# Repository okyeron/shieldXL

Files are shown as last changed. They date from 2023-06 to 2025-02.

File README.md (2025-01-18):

# shieldXL

A rework/remix of the monome norns shield - an open-source/DIY shield for Raspberry Pi boards, providing hardware compatibility with the [norns](https://monome.org/docs/norns) ecosystem. Original designed by monome (brian crabtree, aka @tehn). Remixed in spring 2023 by denki-oto.

__Please be very aware that this project is not directly supported by [monome](https://monome.org). Do not email monome asking for build help, debugging or repairs__

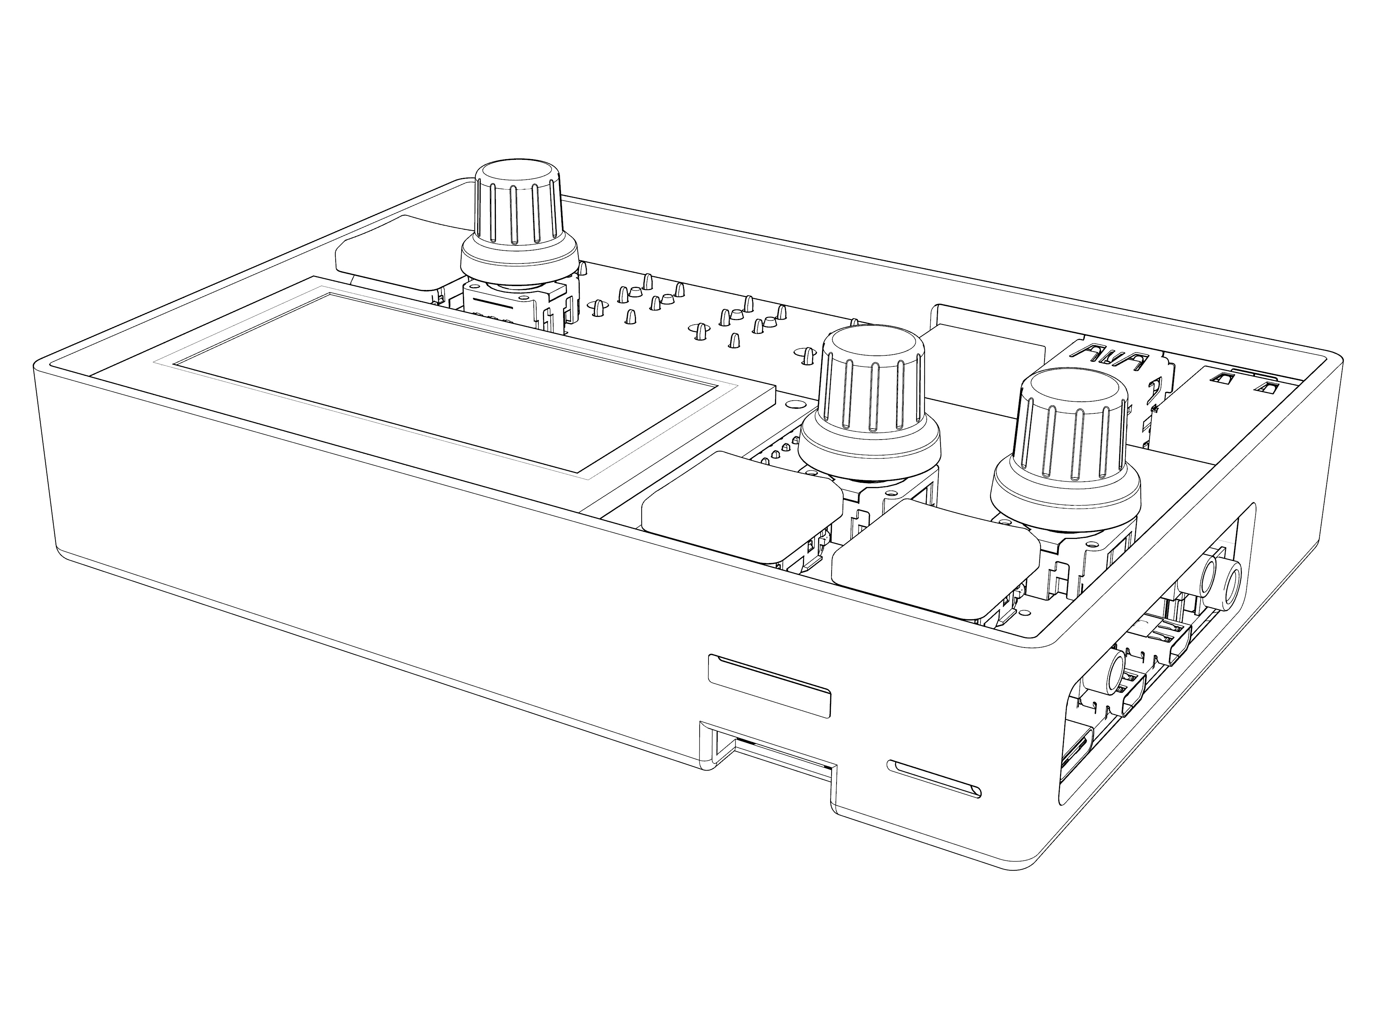
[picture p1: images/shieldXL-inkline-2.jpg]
<# shieldXL-inklinet #>


## specifications

- audio codec: CS4270  
- audio jacks: 6.5mm in and out, line level  
- OLED: NHD-2.7-12864WDW3-M (w/ MOLEX connector)  
- 3x pushbutton switches, 3x rotary encoders  
- dimensions (with enclosure): 138mm x 96mm x 30mm  

## versions

__shieldXL 20230423__
This rework/remix is based on the 210330 version of the norns shield. It uses the same disk image as the 210330 shield with the cs4270 codec.

## documentation

[See the monome website for general norns shield documentation](https://monome.org/docs/norns/shield/) 

## build

[Bill of Materials](bom/BOM.md)

[Build Guide](BUILD.md)

## installation

See [https://monome.org/docs/norns/help/#fresh-shield](https://monome.org/docs/norns/help/#fresh-shield) for installation instructions.  

See [norns releases on github](https://github.com/monome/norns-image/releases/tag/231114-img) for disk images (pre-211028 shield for cs4270 codec).   

Pi3 disk image:    
*  [norns231114-shield-pi3](https://github.com/monome/norns-image/releases/download/231114-img/norns231114-shield-pi3-cs4720.tgz)

Pi4 disk images (Try starting with 220306. If you get a blank screen, try starting over with 231114):  
* Pi4 220306 [norns220306-shield-pi4](https://github.com/monome/norns-image/releases/download/220306/norns220306-shield-pi4-cs4270.tgz)  
* Pi4 231114 [norns231114-shield-pi4](https://github.com/monome/norns-image/releases/download/231114-img/norns231114-shield-pi4-cs4720.tgz)  

REMEMBER TO EXPAND THE DISK IMAGE AFTER INSTALL  
[https://monome.org/docs/norns/shield/#expand-filesystem](https://monome.org/docs/norns/shield/#expand-filesystem)

## enabling hardware midi

```
cd ~
git clone https://github.com/okyeron/shieldXL.git
cd ~/shieldXL 
./install-midi.sh
```
(note - the install script will trigger a reboot)  

Then Edit `/boot/config.txt` 

`sudo nano /boot/config.txt`  

scroll to the bottom of the text and add the following at the end  
 
```
enable_uart=1
dtoverlay=miniuart-bt
dtoverlay=uart0
dtoverlay=midi-uart0
```
Then edit `/boot/cmdline.txt` 

`sudo nano /boot/cmdline.txt`  

and remove `serial0`    
(so change `console=serial0,115200` to `console=115200`)  
and `sudo reboot`  

This will internally connect the shieldXL hardware TRS MIDI jacks to the "Virtual MIDI" port which is accessible from the norns MIDI menu (SYSTEM>DEVICES>MIDI).  

__MIDI Troubleshooting__   

- When checking MIDI functionality, remember that MIDI OUT has a Type A/B switch on the bottom front edge of the main PCB. Try switching that if you're not getting MIDI to your device.

## mods

__Battery Modication__  
Add a Pisugar S Plus battery to your shieldXL:  https://github.com/JGuzak/shieldXl_battery  

## general troubleshooting

- Most soldering problems can be solved simply by reheating solder joints. Bad solders can result in various problems: screen doesn't turn on, knobs/keys don't work.
- Use a good SD card, not a cheap one. If you're having trouble, try using a different card.
- Be sure to use the correct power supply. The pi will not power well from a laptop and you'll get confusing errors. Get a dedicated 3A USB supply, or very high output USB battery.
- see the [norns documentation](https://monome.org/docs/norns/shield/) for help with the software  

## notes

- The shield does not have a dedicated headphone output, but headphones work fine on the main outputs (use the left output jack). The headphone gain level within the norns menu does nothing in this case.
- The battery indication will not function - there is no battery.

## License

[GNU GENERAL PUBLIC LICENSE](LICENSE.txt)

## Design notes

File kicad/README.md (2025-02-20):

# shieldXL 

Designed with [Kicad 8](https://www.kicad.org/)  

ShieldXL-M-20230615  

Based on the 210330 norns shield designed by monome. Remixed/redesigned march 2023 by steven noreyko/denki-oto.  

No official support - do not ask monome for help.   

Kicad files are provided "as-is". Pull requests or modifications to the original repository will not be accepted. No support/assistance can be provided for ordering or building PCBs from these files.

Open Source Hardware GPLv3.  See LICENSE.txt for details.

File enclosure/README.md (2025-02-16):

# shieldXL case/enclosure info

## credits

Models for 3D printing provided by CarlosUnch, John Park, rm, and Steven Noreyko  

Top panel files by Steven Noreyko  

## models for 3d printing

`shieldXL_case_v1.8.6` is the most recent and is optimized for commercial SLS Nylon printing. (from JLCPCB, etc.)  This version will need supports turned on for home FDM printers.  

`shieldXL_case_v1.8.6` also includes new "lids" (top panels) which can accomodate various switch/cap combos.  

`shieldXL_case_v1.4.4-FDM` is probably the simplest model for home FDM printers (PLA, etc.). 

Use the STL file for ordering from 3D printing services or printing yourself.  

Use the STEP file if you're wanting to customize/modify the model.  

Models are setup for M2.5 screws or for M2.5 threaded heat-press inserts.  

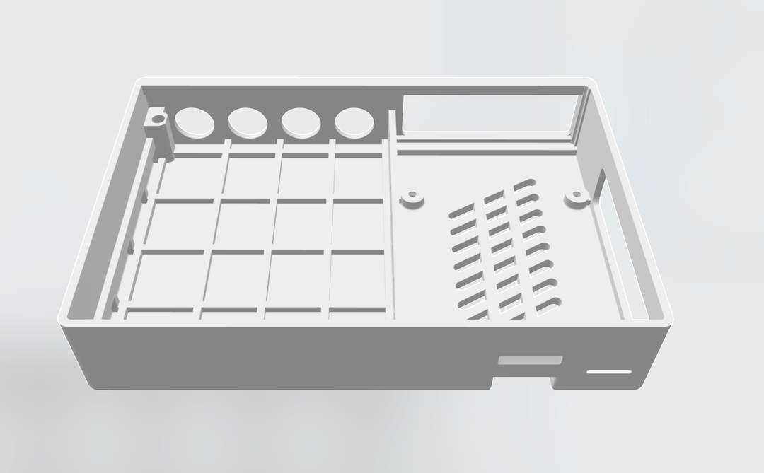
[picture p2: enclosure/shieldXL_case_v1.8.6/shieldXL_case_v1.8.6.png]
<# SLS Nylon caset #> shieldXL_case_v1.8.6
  

## dimensions

pcb dimensions: 132.7mm x 85mm  

top panel dimensions: 138mm x 92mm  

keyswitch holes: 19mm x 19mm

encoder holes: 8mm

mounting holes: 3mm

enclosure dimensions: 138mm x 96mm x 30mm  

## shieldsaver 

design by "rm"  [https://github.com/roge-rm](https://github.com/roge-rm)  

a "decksaver" cover for the standard 3d printed cases.

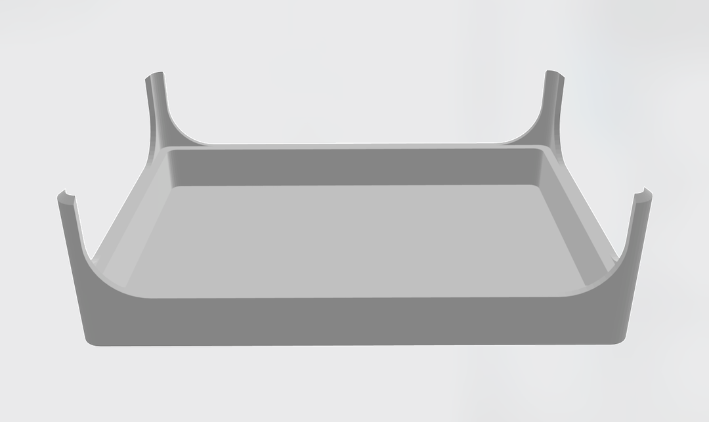
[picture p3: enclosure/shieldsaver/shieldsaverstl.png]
<# shieldsaver stl #> shieldsaver stl


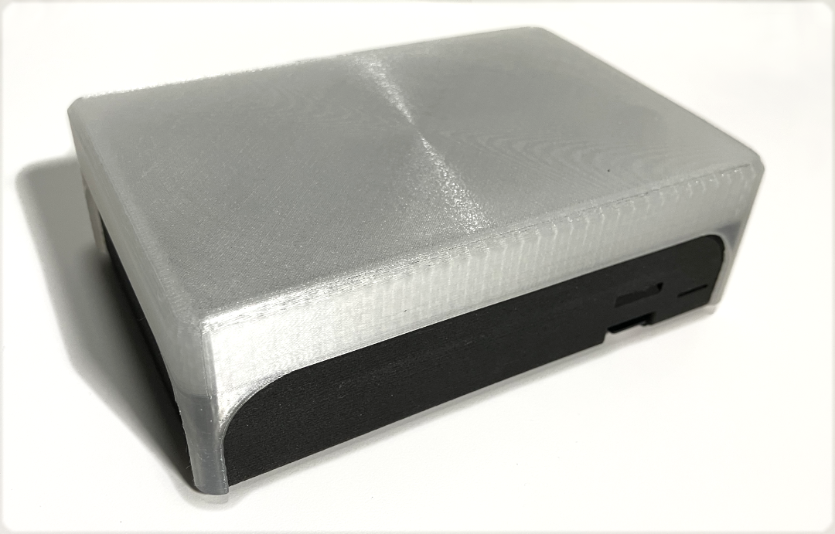
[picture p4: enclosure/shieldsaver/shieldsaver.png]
<# shieldsaver #>


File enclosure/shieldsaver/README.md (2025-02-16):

# shieldXL shieldsaver 

design by "rm"  [https://github.com/roge-rm](https://github.com/roge-rm)  

a "decksaver" cover for the standard 3d printed cases.

<# shieldsaver stl #> shieldsaver stl

<# shieldsaver #>

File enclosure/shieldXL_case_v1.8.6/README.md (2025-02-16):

# shieldXL Case

3D printable case for shieldXL

## License
This 3D model is released under the MIT License. See the LICENSE file for details.

Created by John Park (2023)

You are free to:
- Use the model commercially
- Modify the model
- Distribute the model
- Use the model privately
- Sublicense the model

The only requirement is maintaining the copyright and license notices.

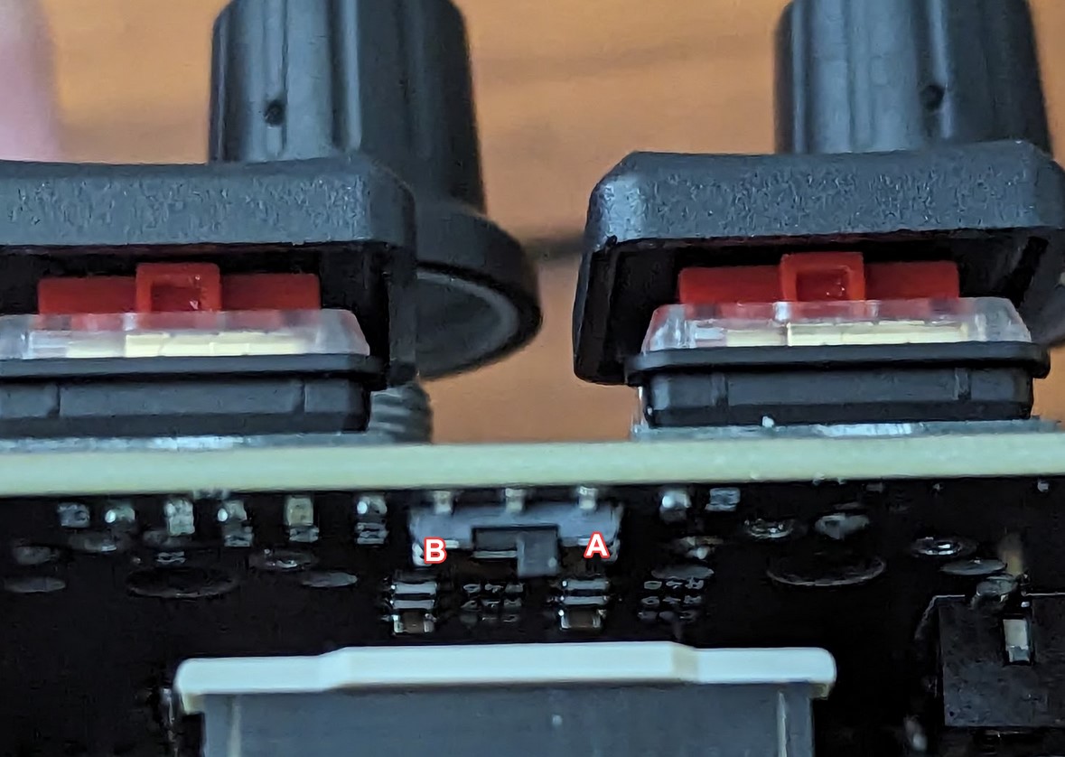
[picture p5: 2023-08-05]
images/midi-switch.jpg

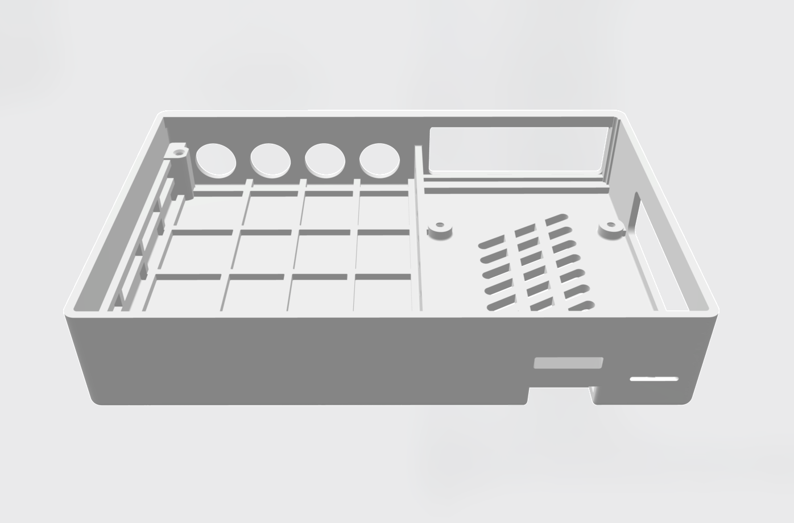
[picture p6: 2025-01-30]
enclosure/shieldXL_case_v1.6.4-SLS-Nylon/SLSNyloncase.png

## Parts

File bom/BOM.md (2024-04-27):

# shieldXL

## Requirements 
* [Raspberry Pi](https://www.raspberrypi.com/) - 3B, 3B+, 4B are supported. With the Pi 4B, the amount of RAM does not help/improve the norns experience. 1GB or 2GB models are great for this project  
* microSD card - use a high quality brand such as SanDisk Class 10  
* Power supply - Monome suggests using the official power supply for your model of Raspberry Pi. The Pi3B has a micro-USB power port and requires at least 2A and 5.25V ideally supplied through a cable with 24AWG or less. The Pi4 has a USB-C power port and 3A / 5.1V is recommended. Lower AWG = lower noise & more stable voltage delivery for better performance. Most consumer USB cables do not meet this spec, so please be sure to keep an eye out. You can also use a portable USB battery if it’s sufficiently large  

## Parts/Components (BOM - Bill of Materials) for pre-assembled boards

If you purchase a kit from denki-oto some of these items may be included. 

[Mouser Cart](https://www.mouser.com/ProjectManager/ProjectDetail.aspx?AccessID=c161b7b4d2) (Does not include switches)  

| Part | QTY | MFG | Part Num | Octopart | Desc |
|---|:--:|-----|-----|-----|-----|
|1528-1785-ND|1|Adafruit Industries|2222|https://octopart.com/2222-adafruit+industries-53880117?r=sp|GPIO Header for Raspberry Pi A+/B+ - 2x20 Female Header|
|NHD-2.7-12864WDW3-M|1|Newhaven Display|NHD-2.7-12864WDW3-M|https://octopart.com/nhd-2.7-12864wdw3-m-newhaven+display-89255061|OLED Displays & Accessories 2.7 in White OLED 128 x 64 MOLEX CONNECTOR|
|PEC11R-4015F-N0024|3|Bourns|PEC11R-4015F-N0024|https://octopart.com/pec11r-4015f-n0024-bourns-26648251|24 Pulse Incremental Mechanical Rotary Encoder w/ 6 mm Flat Shaft|
|550-20311|4|Neutrik|NRJ6HF|https://octopart.com/nrj6hf-neutrik-758943?r=sp|Jack Phone 1/4 in. Stereo|
| SEE BELOW |3|Cherry/Kailh| | |Cherry MX or Kailh Choc switches|
|15167-0358|1|Molex|15167-0358|https://octopart.com/15167-0358-molex-38752501?r=sp|Display FPC Jumper Cables FFC 1.00 - 51mm| 
|Alternate Parts|
|151670356|1|Molex|151670356|https://octopart.com/15167-0356-molex-38752500?r=sp|Display FPC Jumper Cables FFC 1.00 - 31mm. Alternative to 51mm cable, this is a little cleaner but may not be availble. |
|Alternate - Yellow Display|
|NHD-2.7-12864WDY3-M|1|Newhaven Display|NHD-2.7-12864WDY3-M|https://octopart.com/nhd-2.7-12864wdy3-m-newhaven+display-84706411?r=sp|OLED Displays & Accessories 2.7 in Yellow OLED 128 x 64 MOLEX CONNECTOR|
|Optional|
|550-1005|4|Neutrik|NRJ-NUT-B|https://octopart.com/nrj-nut-b-neutrik-141986?r=sp|PLASTIC NUT|

The Display FPC Jumper Cable specs:   
20 Conductor, 1mm pitch, Opposite Side Contacts - either 31mm or 51mm will work. The 31mm is not available at Mouser.  

## Mounting Hardware/Stanoffs

(still a work in progess)  

* 3-4x 11mm F/F for pi  
* 3x 8mm M/F - top side  

Optional (if not using 3d printed case)  
* 2x 16mm F/F - bottom side  

M2.5 thread screws/standoffs are used in kits.  

Knobs are up to you.  
I like these [Re-an-p670-frac-style](https://modularaddict.com/re-an-p670-frac-style-16mm-soft-touch-knob-d-shaft)  

---
## Key switches: 

The PCB is configured to use either Cherry MX or Kailh Choc (V1) switches. If you use Choc's you may want to use the spacer PCB to raise the height of the installed switch.

### Kailh Choc

Kailh Low Profile Choc Switches  

Some sources for keycaps and switches:  
US [MKUltra](https://mkultra.click/choc-switches)  
EU [Keycapsss](https://keycapsss.com/switchestester/switches/65/kailh-low-profile-choc-switches-v1)  
AU [keebd](https://keebd.com/collections/choc-switches)  

Also from Adafruit:  
[https://www.adafruit.com/product/5113 ](https://www.adafruit.com/product/5113)   
[https://octopart.com/5113-adafruit+industries-119996176?r=sp](https://octopart.com/5113-adafruit+industries-119996176?r=sp)  

| Color	| Type	| Actuation Force	| Actuation Travel	| Total Travel |
|-----|----|:---:|:---:|:---:|
|White	|	Clicky	|	60±10gf	|	1.5±0.5mm	|	3.0±0.5mm |
|Brown	|	Tactile	|	60±10gf	|	1.5±0.5mm	|	3.0±0.5mm |
|Red	|	Linear	|	50±10gf	|	1.5±0.5mm	|	3.0±0.5mm |
|Black	|	Linear	|	60±10gf	|	1.5±0.5mm	|	3.0±0.5mm |
|Pro Red	|	Linear	|	35±10gf	|	1.5±0.5mm	|	3.0±0.5mm |
|gChoc*	|	Linear	|	20±10gf	|	1.5±0.5mm	|	3.0±0.5mm |
|Robin	|	Clicky	|	57±10gf	|	1.5±0.5mm	|	3.0±0.5mm |
|Silver	|	Linear	|	40±10gf	|	1.5±0.5mm	|	3.0±0.5mm |
|Pink*	|	Linear	|	20±10gf	|	1.5±0.5mm	|	3.0±0.5mm |

### MX 

Any of the Cherry MX (or MX footprint) switches will work. Red/SilentRed/Blue/Brown/Black/SpeedSilver.  
Red is linear (45g). Blue is clicky & tactile (50g). Brown is tactile (45g). Black is similar to Red but 60g actuation force. SpeedSilver (shorter key travel for gamers) are linear and __Expensive__( 45g)

Cherry MX RGB part numbers:  

| Name/Color  | Part num | Type | Actuation Force |
|-----|----|-----|----|
|SilentRed |[MX3A-L1NA](https://www.mouser.com/ProductDetail/CHERRY/MX3A-L1NA/?qs=F5EMLAvA7IA6PAS7ry3I9w%3D%3D)| linear | (45g) |
|Red	|MX1A-L1NA| linear | (45g) |
|SilentBlack |[MX3A-11NA](https://www.mouser.com/ProductDetail/CHERRY/MX3A-11NA/?qs=F5EMLAvA7ICizK1XKjfN9w%3D%3D)| linear | (60g) |
|Black	|MX1A-11NA| linear | (60g) |
|Brown	|[MX1A-G1NA](https://www.mouser.com/ProductDetail/540-MX1A-G1NA/)| tactile | (45g) |
|Blue	|MX1A-E1NA| clicky & tactile | (50g) |
|Silver	|[MX1A-51NA](https://www.mouser.com/ProductDetail/CHERRY/MX1A-51NA/?qs=F5EMLAvA7IB4ByA0zXdBkg%3D%3D)| linear | (45g) |

Reference: https://www.mouser.com/pdfDocs/cherrykeyswitches.pdf

---
## Keycaps: 

NOTE - Chocs have specific keycaps and are not compatible with MX switches.

#### Chocs keycaps

MBK profile caps are great:  
US [MKUltra](https://mkultra.click/search.php?search_query=mbk&section=product)  
EU [Keycapsss](https://keycapsss.com/keyboard-parts/keycaps/182/mbk-dye-color-choc-low-profile-keycap)  
AU [keebd](https://keebd.com/products/mbk-low-profile-keycaps)  

Work Louder - wrk-dime  
[https://worklouder.cc/shop/wrk-dime/](https://worklouder.cc/shop/wrk-dime/)  

#### MX keycaps

Any MX-compatible keycaps will work, but DSA profile caps work well for this application.

[DSA "Dolch" Keyset (Two Shot) "Windowed" Keys](https://pimpmykeyboard.com/dsa-dolch-keyset-two-shot/) (choose the __LED Kit__ option).  

[Flashquark Translucent DSA Keycaps](https://flashquark.com/product/translucent-dsa-keycaps/) (in Black, White, Clear, Blue, Red) - __50 per pack__. ($12.99-$15.99 per pack)

[Blue Hat 1U DSA Blank Printed Keycaps PBT Keycaps](https://www.amazon.com/gp/product/B07SJKMNWC) (Gray Translucent) - __37 per pack__. ($15.55 per pack and prime shipping)  
(about the same as the black ones from Flashquark above)

[Maxkeyboard Black Translucent MX Blank](https://www.maxkeyboard.com/black-translucent-cherry-mx-blank-keycap-set-for-esc-w-a-s-d-or-e-s-d-f-and-arrow-keys.html) (pack of 9).

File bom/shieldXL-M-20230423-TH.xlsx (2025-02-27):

Query | Qty | Manufacturer | MPN | Octopart URL | Part Description | Description | Schematic Reference
1528-1969-ND | 1 | Adafruit Industries | 2222 | https://octopart.com/2222-adafruit+industries-53880117?r=sp | GPIO Header for Raspberry Pi A+/B+ - Tall 2x20 Female Header | RASPI_BOARD_B+#_E3 | X1
NHD-2.7-12864WDW3-M | 1 | Newhaven Display | NHD-2.7-12864WDW3-M | https://octopart.com/nhd-2.7-12864wdw3-m-newhaven+display-89255061 | OLED Displays & Accessories 2.7 in White OLED 128 x 64 MOLEX CONNECTOR
PEC11R-4015F-N0024 | 3 | Bourns | PEC11R-4015F-N0024 | https://octopart.com/pec11r-4015f-n0024-bourns-26648251 | 24 Pulse Incremental Mechanical Rotary Encoder w/ 6 mm Flat Shaft | Through Hole | ENC
550-20311 | 4 | Neutrik | NRJ6HF | https://octopart.com/nrj6hf-neutrik-758943?r=sp | Jack Phone 1/4 in. Stereo | Through Hole
15167-0358 | 1 | Molex | 15167-0358 | https://octopart.com/15167-0358-molex-38752501?r=sp | Display FPC Jumper Cables FFC 1.00 - 51mm
 | 3 | Kailh Choc | 5113 | https://octopart.com/5113-adafruit+industries-119996176?r=sp | Cherry MX or Kailh Choc switches
 | 3 | Keycaps
 | 3 | Knobs
 | 1 | Pcb panel
Alternate FPC Cable from digikey (shorter - 30mm)
151670356 | 1 | Molex` | 151670356 | https://octopart.com/15167-0356-molex-38752500?r=sp | Display FPC Jumper Cables FFC 1.00 - 31mm
 | 3 | Kailh/Cherry MX Red | 4952 | https://octopart.com/4952-adafruit+industries-117339661?r=sp

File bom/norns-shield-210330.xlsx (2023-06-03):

Query | Qty | Manufacturer | MPN | Octopart URL | Part Description | Description | Schematic Reference
TSW-120-05-T-S | 1 | Samtec | TSW-120-05-T-S | https://octopart.com/tsw-120-05-t-s-samtec-271715 | Headers & Wire Housings Classic PCB Header Strips, 0.100 pitch | OLED HEADER | U$1
TPS793475DBVR | 1 | Texas Instruments | TPS793475DBVR | https://octopart.com/tps793475dbvr-texas+instruments-525242 | Ldo Voltage Regulator, 4.75V, 0.2A, 5-SOT-23, Full Reel | TPS793 | U11
RC0603FR-07590RL | 2 | Yageo | RC0603FR-07590RL | https://octopart.com/rc0603fr-07590rl-yageo-1229374 | Res Thick Film 0603 590 Ohm 1% 0.1W(1/10W) ±100ppm/C Pad SMD T/R | 590 | R12, R14
RC0603FR-074K99L | 2 | Yageo | RC0603FR-074K99L | https://octopart.com/rc0603fr-074k99l-yageo-55458490 | Res General Purpose Thick Film 0603 4.99k Ohm 1% 1/10W ±100ppm/°C Molded Paper T/R | 4.99k | R7, R9
RC0603FR-0710KL | 24 | Yageo | RC0603FR-0710KL | https://octopart.com/rc0603fr-0710kl-yageo-40025538 | Res General Purpose Thick Film 0603 10K Ohm 1% 1/10W ±100ppm/°C Molded SMD Paper T/R | 10k | R1, R2, R3, R4, R8, R10, R11, R13, R15, R26, R28, R29, R32, R34, R35, R38, R40, R41, R44, R45, R46, R47, R48, R49
PVA1 OA H1 1.2N V2 | 3 | C&K Components | PVA1OAH11.2NV2 | https://octopart.com/pva1oah11.2nv2-c%26k+components-47645791 | Switch Push Button DPST Square Button 0.1A 32VDC Momentary Contact PC Pins Thru-Hole | PVA1 | SW1, SW2, SW3
PEC11R-4015F-N0024 | 3 | Bourns | PEC11R-4015F-N0024 | https://octopart.com/pec11r-4015f-n0024-bourns-26648251 | 24 Pulse Incremental Mechanical Rotary Encoder w/ 6 mm Flat Shaft | Through Hole | ENC
NHD-2.7-12864WDY3 | 1 | Newhaven Display | NHD-2.7-12864WDY3 | https://octopart.com/nhd-2.7-12864wdy3-newhaven+display-84706410 | OLED Displays & Accessories 2.7 in Yellow OLED 128 x 64
GRM1885C1H272JA01D | 2 | Murata | GRM1885C1H272JA01D | https://octopart.com/grm1885c1h272ja01d-murata-196902 | Multilayer Ceramic Capacitor, 2700 pF, 50 V, ± 5%, C0G (NP0), 0603 [1608 Metric] | 2700p COG | C15, C17
GRM1885C1H221JA01D | 2 | Murata | GRM1885C1H221JA01D | https://octopart.com/grm1885c1h221ja01d-murata-196153 | Multilayer Ceramic Capacitor, 220 pF, 50 V, ± 5%, C0G (NP0), 0603 [1608 Metric] | 220p COG | C11, C13
GRM21BR61E106KA73L | 5 | Murata | GRM21BR61E106KA73L | https://octopart.com/grm21br61e106ka73l-murata-11231261 | Multilayer Ceramic Capacitor, 10 uF, 25 V, ± 10%, X5R, 0805 [2012 Metric] | 10u | C2, C5, C10, C12, C43
CS4270-CZZ | 1 | Cirrus Logic | CS4270-CZZ | https://octopart.com/cs4270-czz-cirrus+logic-428038 | Audio Codec 2ADC / 2DAC 24-Bit 24-Pin TSSOP Rail | CS4270 | U1
CGA4J3X5R1E335M125AB | 2 | TDK | CGA4J3X5R1E335M125AB | https://octopart.com/cga4j3x5r1e335m125ab-tdk-28170883 | Multilayer Ceramic Capacitor, 3.3 uF, 25 V, ± 20%, X5R, 0805 [2012 Metric] | 3.3u | C14, C16
CC0603KRX7R9BB103 | 11 | Yageo | CC0603KRX7R9BB103 | https://octopart.com/cc0603krx7r9bb103-yageo-192938 | Multilayer Ceramic Capacitor, 0.01 uF, 50 V, ± 10%, X7R, 0603 [1608 Metric] | 10n | C3, C35, C36, C38, C39, C41, C42, C44, C45, C46, C88
C3216X5R1E476M160AC | 2 | TDK | C3216X5R1E476M160AC | https://octopart.com/c3216x5r1e476m160ac-tdk-25947783 | Multilayer Ceramic Capacitor, 47 uF, 25 V, ± 20%, X5R, 1206 [3216 Metric] | 47u | C7, C9
BLM21PG331SN1D | 1 | Murata | BLM21PG331SN1D | https://octopart.com/blm21pg331sn1d-murata-755248 | Ferrite Beads Multi-Layer 330Ohm 25% 100MHz 1.5A 70mOhm DCR 0805 Automotive Paper T/R | FERRITE | L3
ASFL1-12.288MHZ-EC-T | 1 | Abracon | ASFL1-12.288MHZ-EC-T | https://octopart.com/asfl1-12.288mhz-ec-t-abracon-317620 | Oscillator XO 12.288MHz 50ppm 15pF (Stability) HCMOS/TTL 60% 3.3V 4-Pin SMD T/R | ASFL-12.288mhz | Q1
4832.233 | 2 | Schurter | 4832.233 | https://octopart.com/4832.2330-schurter-6626217 | Conn 3.5MM Audio Jack SKT 4 POS Solder RA Thru-Hole 4 Terminal 1 Port | JACK-TRS-SW | J-IN, J-OUT
1528-1969-ND | 1 | Adafruit Industries | 1992 | https://octopart.com/1992-adafruit+industries-53880115 | GPIO Header for Raspberry Pi A+/B+ - Tall 2x20 Female Header | RASPI_BOARD_B+#_E3 | X1
311-1343-2-ND | 6 | Yageo | CC0603ZRY5V9BB104 | https://octopart.com/cc0603zry5v9bb104-yageo-4507169 | Multilayer Ceramic Capacitor, 0.1 uF, 50 V, -20, +80%, Y5V, 0603 [1608 Metric] | 100n | C1, C4, C6, C8, C47, C63

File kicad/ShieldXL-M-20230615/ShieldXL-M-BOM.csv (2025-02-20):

Reference | Value | Datasheet | Footprint | Qty | DNP | # | Description
C1,C4,C6,C8,C18,C47,C63 | 100n |  | ShieldXL:C0603 | 7 |  | 1
C2,C5,C10,C12,C43 | 10u |  | ShieldXL:C0805 | 5 |  | 2
C3,C35,C36,C38,C39,C41,C42,C44,C45,C46,C88 | 10n |  | ShieldXL:C0603 | 11 |  | 3
C7,C9 | 47u |  | ShieldXL:C1206 | 2 |  | 4
C11,C13 | 220p COG |  | ShieldXL:C0603 | 2 |  | 5
C14,C16 | 3.3u |  | ShieldXL:C0805 | 2 |  | 6
C15,C17 | 2700p COG |  | ShieldXL:C0603 | 2 |  | 7
D1 | RED |  | ShieldXL:CHIPLED_0603_NOOUTLINE | 1 |  | 8
D2 | BLUE |  | ShieldXL:CHIPLED_0603_NOOUTLINE | 1 |  | 9
E1,E2,E3 | ENC |  | ShieldXL:PEC11RN | 3 | DNP | 10
J1,J2,J4,J5 | NRJ6HF | https://www.neutrik.com/en/product/nrj6hf | ShieldXL:Jack_6.35mm_Neutrik_NRJ6HF_Horizontal | 4 |  | 11
J3,J6 | PJ-320B |  | ShieldXL:LUOYANG-DISHANG_PJ-320B | 2 |  | 12
L1,L2,R21 | DNP |  | -- mixed values -- | 3 | DNP | 13
L3 | FERRITE |  | ShieldXL:L0805 | 1 |  | 14
Q1 | ASFL1-12.288MHZ-LCS-T |  | ShieldXL:ASF | 1 |  | 15
R1,R2,R3,R4,R8,R10,R11,R13,R15,R26,R28,R29,R32,R34,R35,R38,R40,R41,R44,R45,R46,R47,R48,R49 | 10k |  | ShieldXL:R0603 | 24 |  | 16
R5 | 470Ω |  | ShieldXL:R0603 | 1 |  | 17
R6,R16 | 220Ω |  | ShieldXL:R0603 | 2 |  | 18
R7,R9 | 4.99k |  | ShieldXL:R0603 | 2 |  | 19
R12,R14 | 590 |  | ShieldXL:R0603 | 2 |  | 20
R17,R18,R19 | 47Ω |  | ShieldXL:R0603 | 3 |  | 21
R20 | 15Ω |  | ShieldXL:R0603 | 1 |  | 22
S1 | EG1390B |  | ShieldXL:SOP250P600X400-6N | 1 |  | 23
SW1,SW2,SW3 | PVA1 |  | ShieldXL:Choc_MX_combo | 3 | DNP | 24
U$1 | FPC1M20P-B310 |  | ShieldXL:F-FPC1M20P-B310 | 1 |  | 25
U1 | CS4270 |  | ShieldXL:TSSOP24 | 1 |  | 26
U2 | HCPL-0631-500E |  | ShieldXL:SSOP-8_3.9x5.05mm_P1.27mm | 1 |  | 27
U11 | TPS793475DBVR |  | ShieldXL:SSOP5 | 1 |  | 28
X1 | RASPI_BOARD_B+#_E3 |  | ShieldXL:RASPI_BOARD_B+_EDGES_3DRILL | 1 | DNP | 29

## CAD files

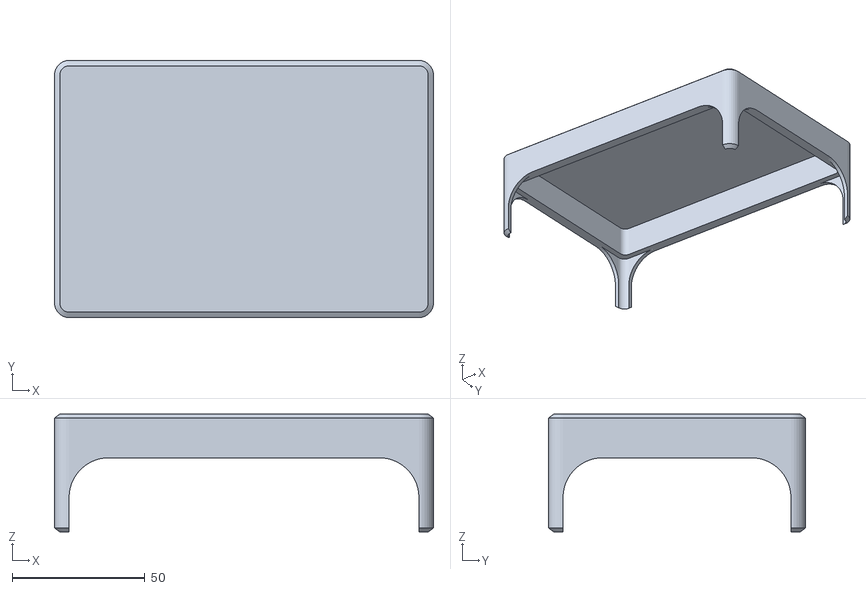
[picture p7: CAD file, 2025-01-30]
enclosure/shieldsaver/shieldsaver_tall_v2.stl
143.0 x 97.0 x 44.5

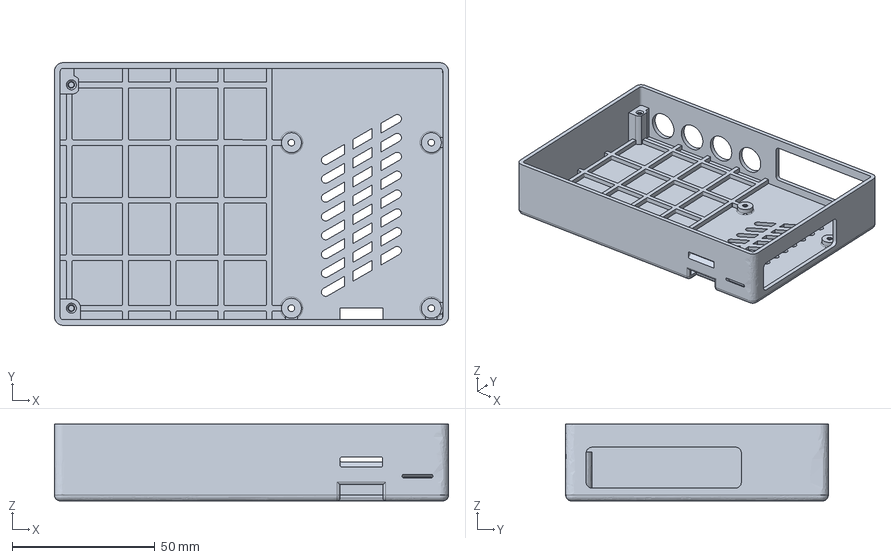
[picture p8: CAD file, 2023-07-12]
enclosure/shieldXL_case_v1.4.4-FDM/shieldXL_case_jp_v1.4.4_threaded.step
138.0 x 92.0 x 26.9 mm

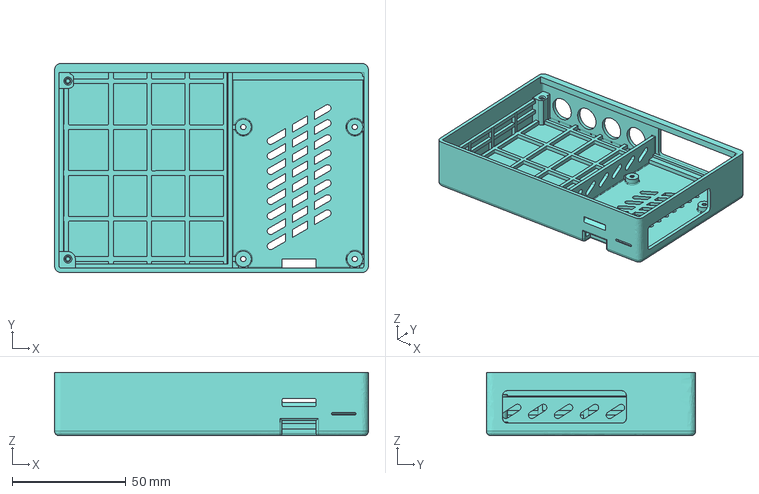
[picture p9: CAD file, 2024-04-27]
enclosure/shieldXL_case_v1.6.4-SLS-Nylon/shieldXL_case_jp_v1.6.4.step
138.0 x 92.0 x 27.9 mm

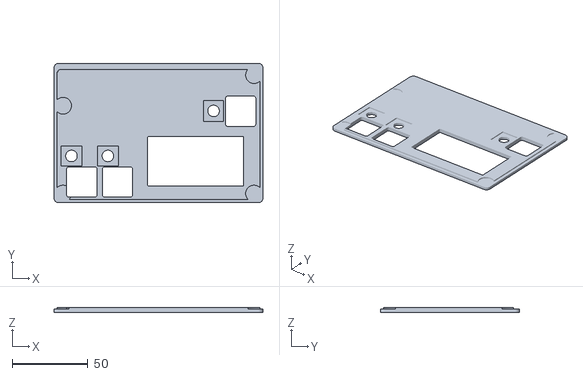
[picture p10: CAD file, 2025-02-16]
enclosure/shieldXL_case_v1.8.6/shieldXL_lid_jp_v1.8.6_mx.stl
138.0 x 92.0 x 3.00

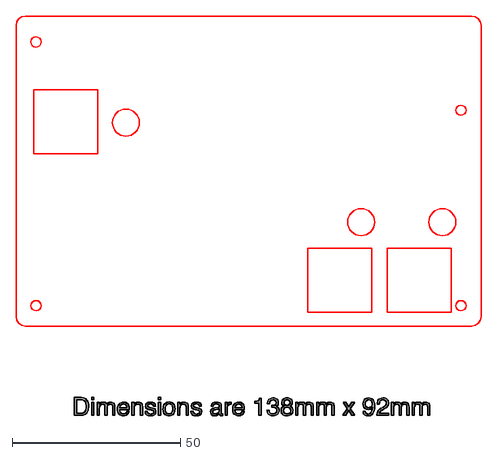
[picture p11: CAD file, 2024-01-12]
enclosure/top-panel/ShieldXL-M-top-panel-no-window.dxf
138.0 x 118.6

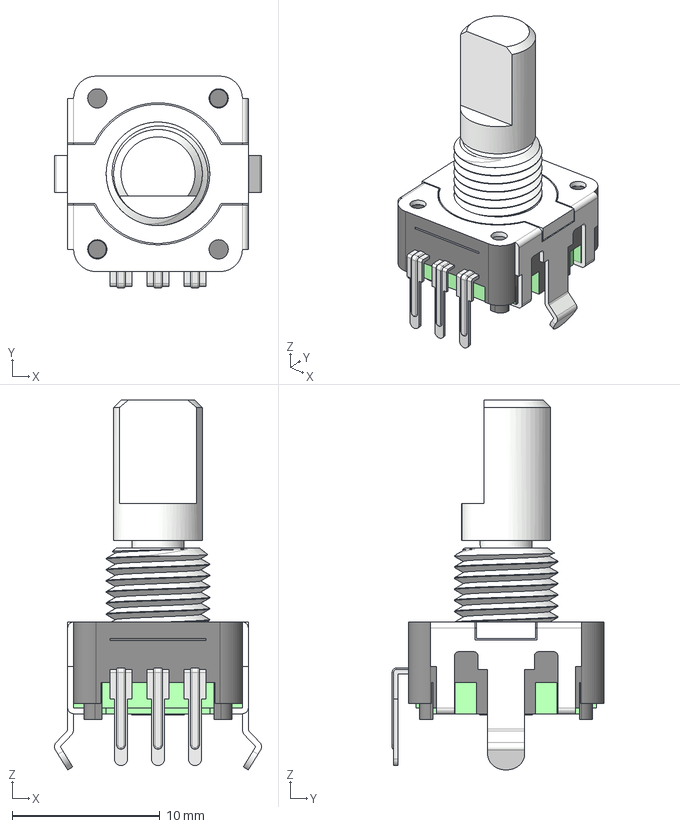
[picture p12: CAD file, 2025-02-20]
kicad/ShieldXL-M-20230615/3dmodels/SW-PEC11R-4215F-N0024.stp
14.0 x 14.3 x 25.0 mm

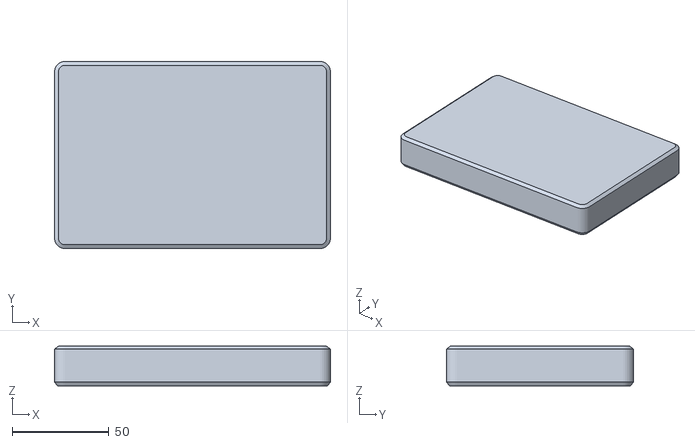
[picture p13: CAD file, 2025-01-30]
enclosure/shieldsaver/shieldsaver_slim_v2.stl
143.0 x 97.0 x 20.5

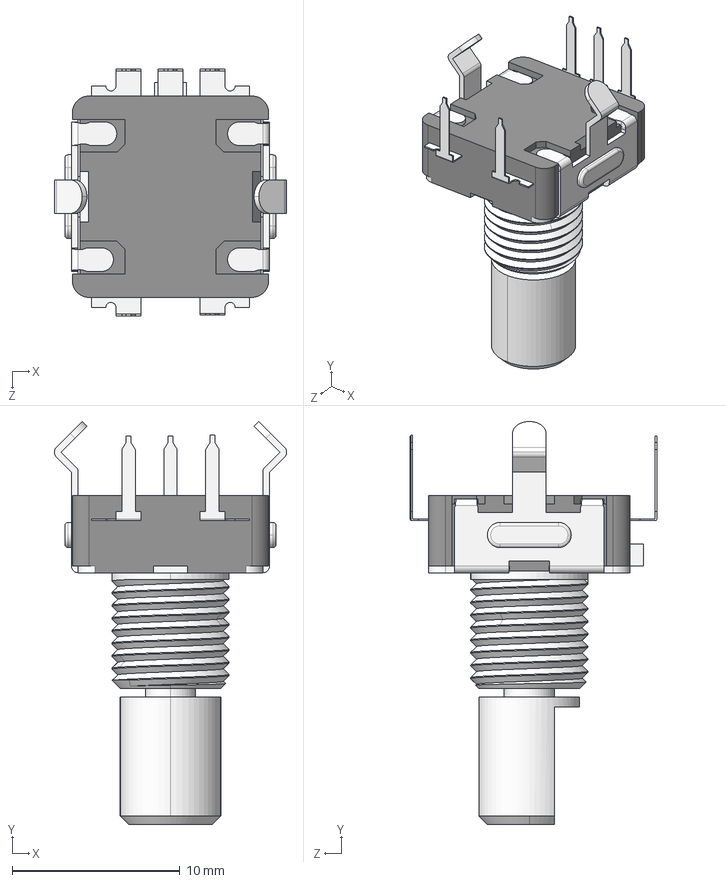
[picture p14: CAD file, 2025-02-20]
kicad/ShieldXL-M-20230615/3dmodels/PEC11L-4115F-S0020.stp
13.8 x 24.0 x 14.7 mm

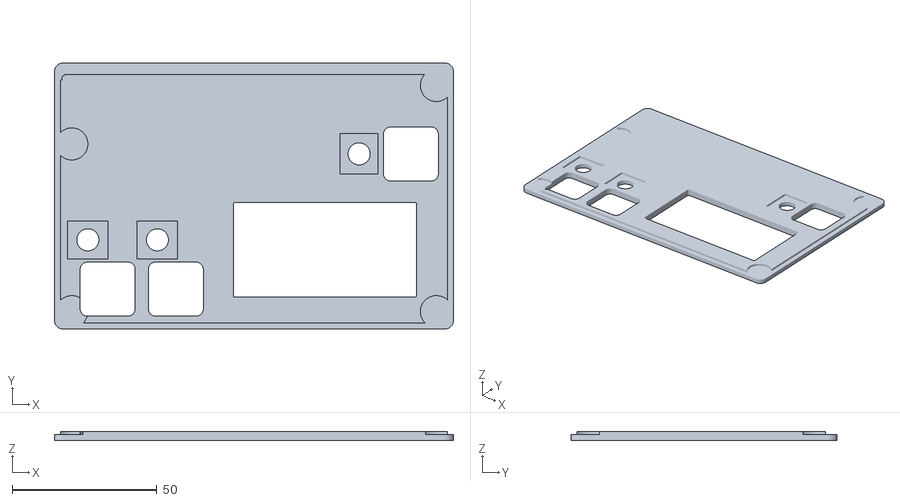
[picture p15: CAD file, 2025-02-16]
enclosure/shieldXL_case_v1.8.6/shieldXL_lid_jp_v1.8.6_choc.stl
138.0 x 92.0 x 3.00

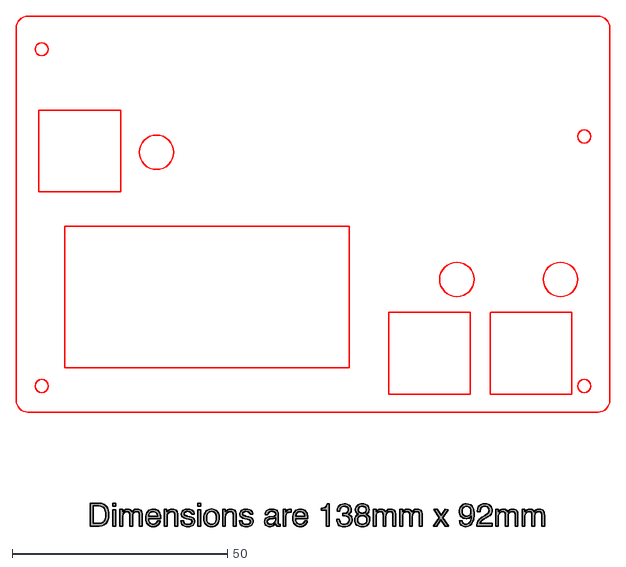
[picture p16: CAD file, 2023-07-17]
enclosure/top-panel/ShieldXL-M-top-panel-19mm.dxf
138.0 x 118.6

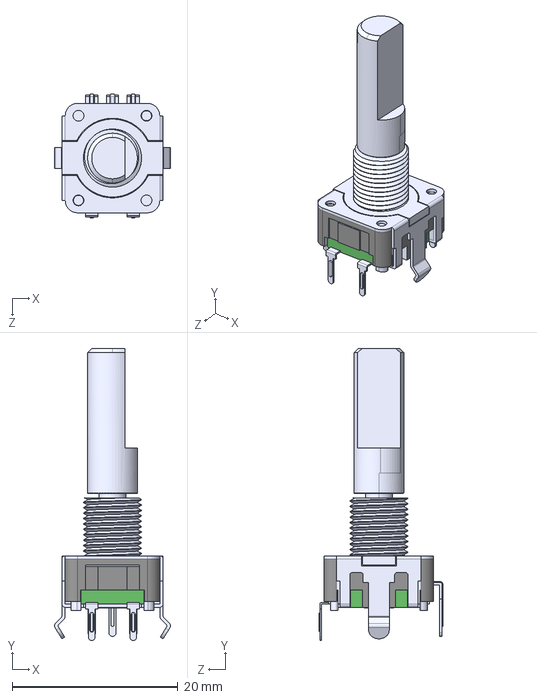
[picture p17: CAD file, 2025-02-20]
kicad/ShieldXL-M-20230615/3dmodels/PEC11R-4015F-S0024.stp
14.0 x 35.2 x 14.9 mm

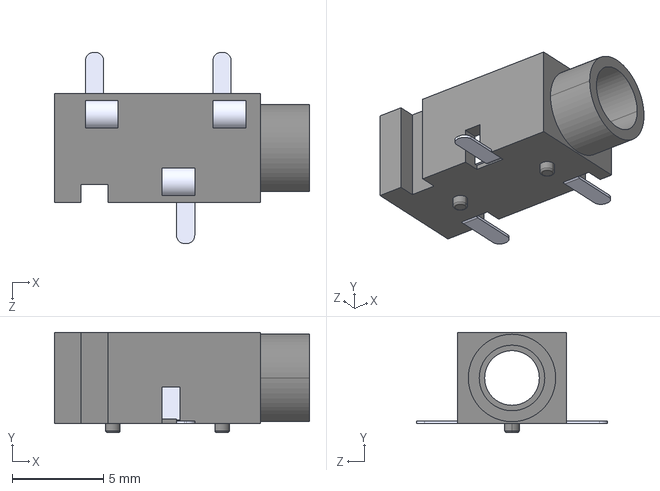
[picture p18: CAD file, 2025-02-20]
kicad/ShieldXL-M-20230615/3dmodels/PJ-320B.step
14.0 x 5.50 x 10.5 mm

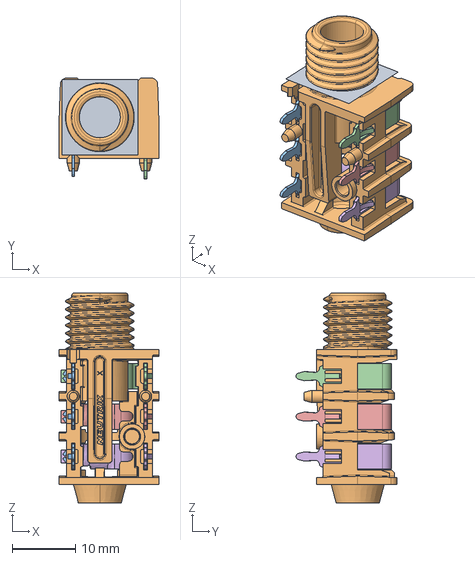
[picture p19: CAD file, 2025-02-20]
kicad/ShieldXL-M-20230615/3dmodels/nrj6hf.stp
15.8 x 16.0 x 33.2 mm

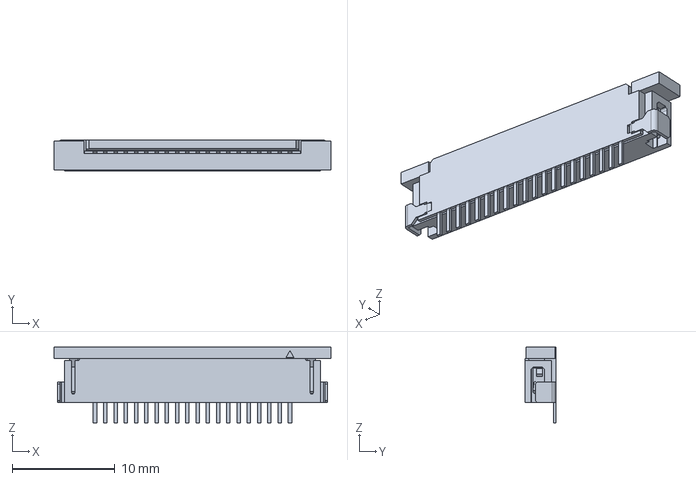
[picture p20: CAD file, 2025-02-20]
kicad/ShieldXL-M-20230615/3dmodels/52271-2079.stp
27.0 x 3.00 x 7.40 mm

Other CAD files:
enclosure/top-panel/shieldXLplate-v2.stl
enclosure/shieldXL_case_v1.8.6/shieldXL_lid_jp_v1.8.6_choc-w-screw.stl
enclosure/shieldXL_case_v1.8.6/shieldXL_lid_jp_v1.8.6_mx-w-screw.stl
enclosure/shieldXL_case_v1.5.1-SLS-Nylon/shieldXL_case_jp_v1.5.1.step
enclosure/shieldXL_case_v1.6.1-SLS-Nylon/shieldXL_case_jp_v1.6.1.step

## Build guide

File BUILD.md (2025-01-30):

# shieldXL Build Guide

[Video build guide playlist](https://youtube.com/playlist?list=PLYhX2rtncmtN1OSebuMCquus0ssT5jDe1)

PCBs sourced from denki-oto will include a few extras:

* PCB spacers for Choc switches (see build notes below) - not needed for MX switches  
* Acrylic display spacer - this is a 3mm thick acrylic spacer to support the OLED display

For soldering help/tips see this awesome [guide from Adafruit](https://learn.adafruit.com/adafruit-guide-excellent-soldering/common-problems)  

## Build

[Video instructions](https://youtu.be/Cyyh8wZTWDU)

### Pi header

The pi-header attaches from __the bottom__ of the PCB

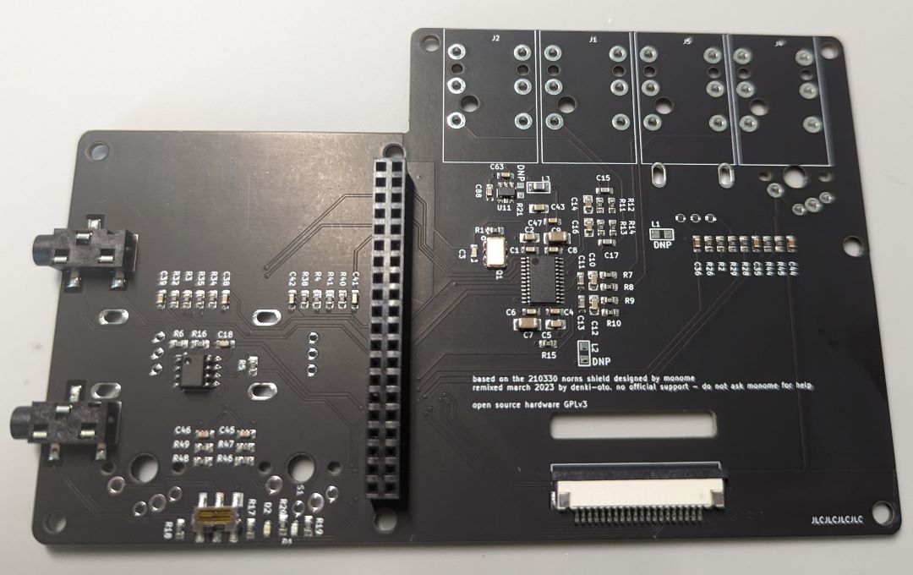
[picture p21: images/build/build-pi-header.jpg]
pi header


### Switches

If using Choc switches, use included PCB spacers between the switch and the main PCB. There should still be enough pin sticking through to solder these in one go. These are meant to raise the switch body up to a better level with the encoders.  

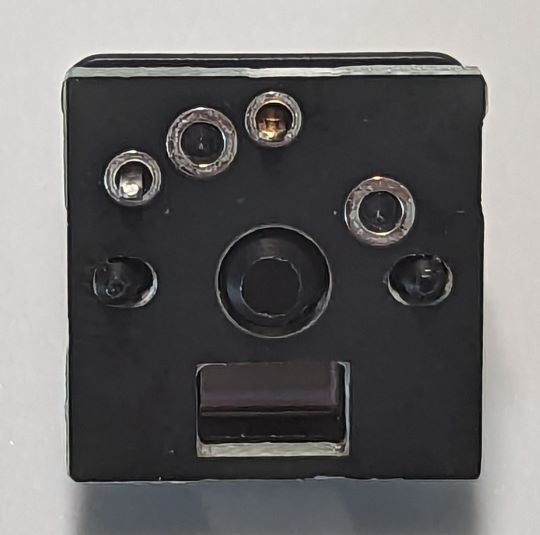
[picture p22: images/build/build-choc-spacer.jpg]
choc spacer


__NOTE__ - be sure the switch position is nice and square in relation to the other parts - not rotated at all - so your keycaps don't end up looking wonky in the end.  

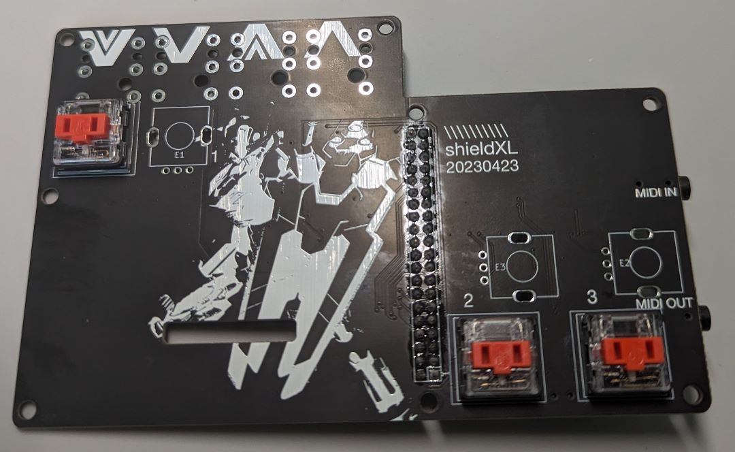
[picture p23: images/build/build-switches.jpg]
switches


### Jacks

The jacks attach from __the bottom__ of the PCB

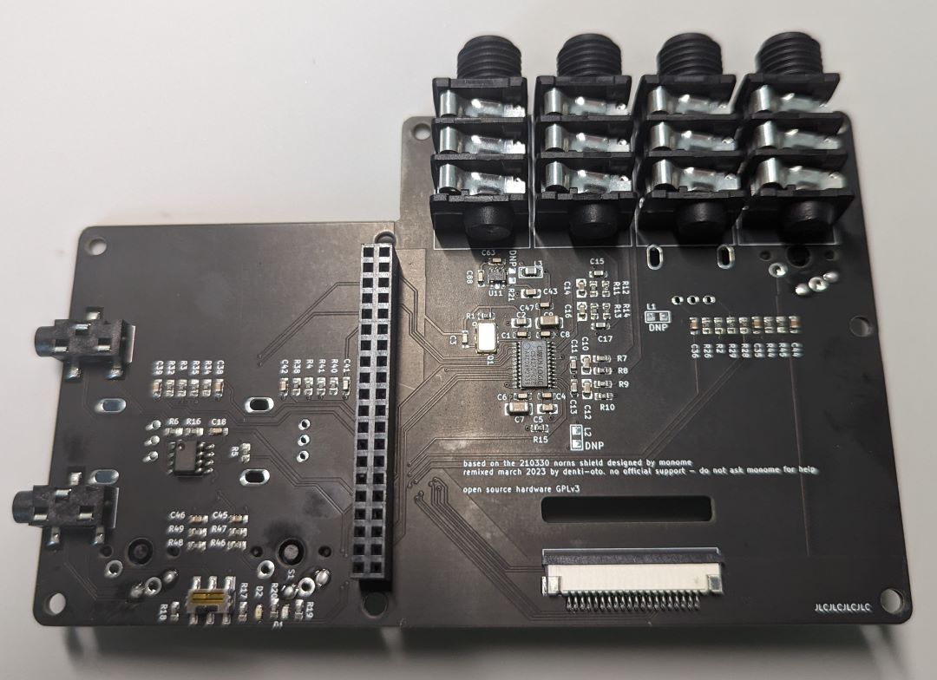
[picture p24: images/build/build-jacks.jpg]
jacks


### Encoders

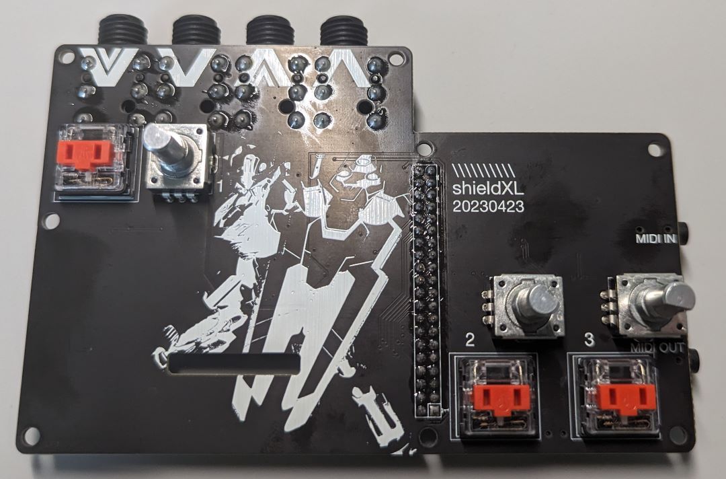
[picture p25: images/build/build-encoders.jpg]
encoders


### Attaching the display

[Video instructions](https://youtu.be/nq_Z90EFWEE)

The OLED uses an FPC cable to attach. This runs through the hole in the PCB to the connector on the bottom.

* Attach the cable to the display first and then connect it to the board
* Slide the connector open with a spudger or a fingernail  
* Insert the FPC cable with the blue side facing up (away from the PCB)  
* Be sure the cable is inserted properly - with about half the blue portion showing  
* Snap the connector closes with your finger/fingernail  
* The angle needed to slide the cable inserted can sometimes be tricky  
* Be sure to put the display spacer in place before final attachment of the FPC cable  
* It can be tricky to get that in place with the shorter (30mm) FPC cable
* The bottom right screw hole can be used to secure the display to the main board and Pi  

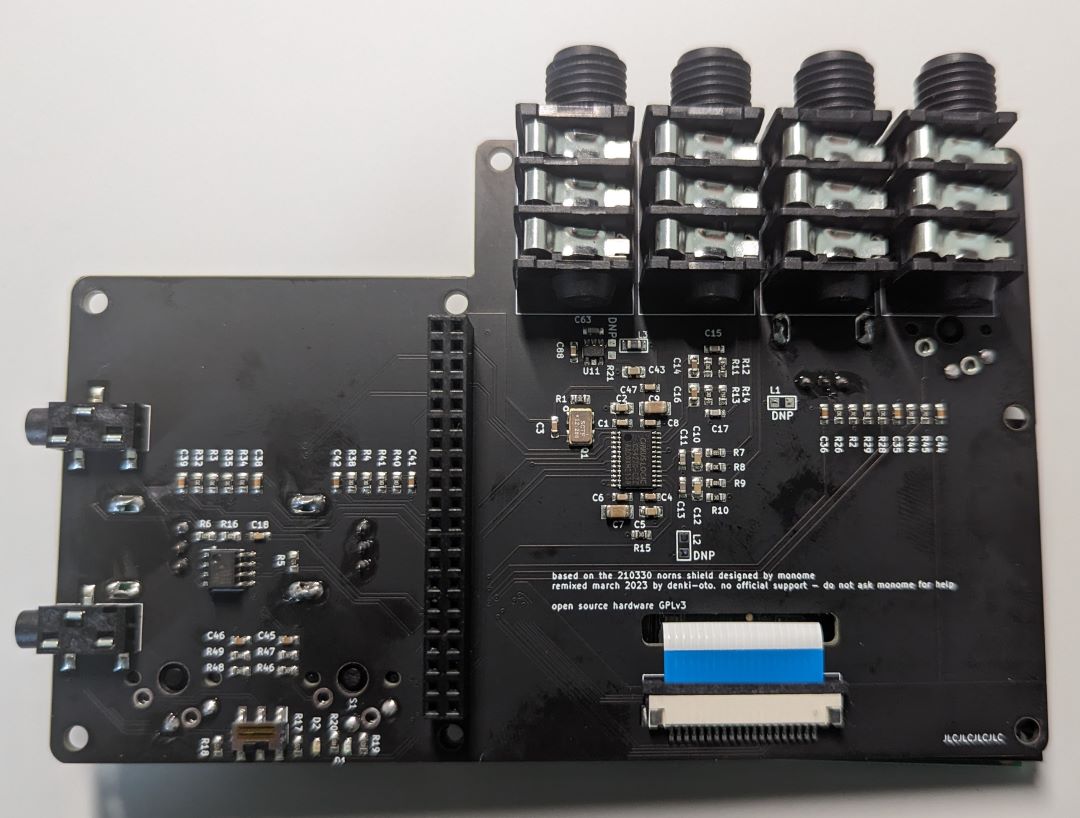
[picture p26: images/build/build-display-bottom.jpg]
display bottom


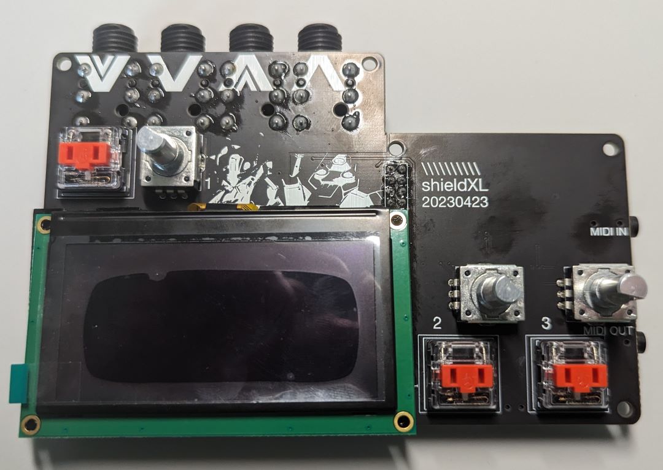
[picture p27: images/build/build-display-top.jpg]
display top


### Attaching the Pi / Case Assembly

[Video instructions](https://youtu.be/K84_22LJrQo)

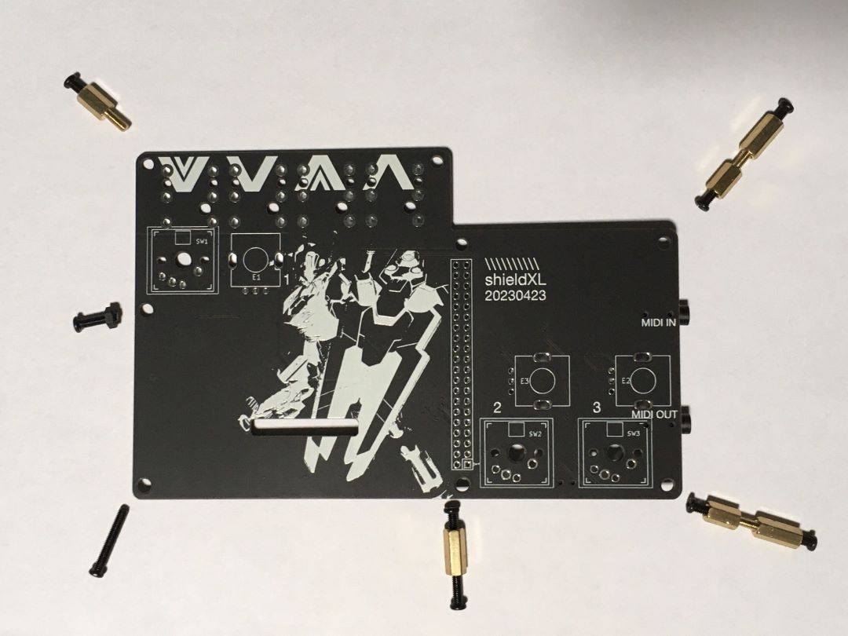
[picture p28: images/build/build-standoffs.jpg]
standoffs


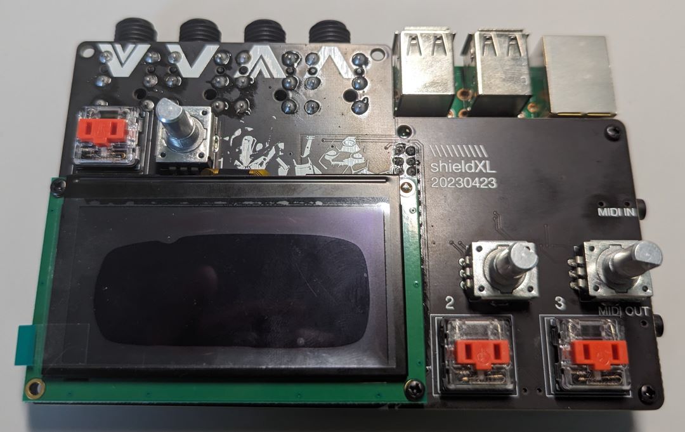
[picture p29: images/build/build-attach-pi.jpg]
attach pi


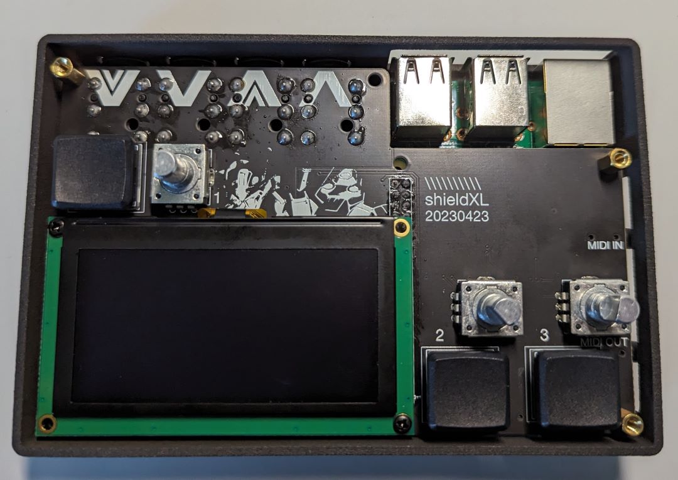
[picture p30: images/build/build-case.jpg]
case


### Attach the top panel

IMPORTANT - the acrylic top panels in the standard kit ship with a paper backing to prevent damage. PCB panels have an acrylic window insert - also with paper backing. Remove the paper backing from both sides.  

Use the remaining screws (3x 6mm long, and 1x 16mm long) to attach the top panel. Do not over-tighten screws.

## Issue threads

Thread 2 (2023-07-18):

Standoffs

slowscape, 2023-07-18:
Looking at the BOM, the standoffs don't seem to note the thread size. Does it matter?

okyeron, 2023-08-05:
M2.5 is what I've been using. I'll update the bom.

Closed 2023-08-05.

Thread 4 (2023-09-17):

Open sourcing of the hardware

Pastitas, 2023-09-17:
Hi!
I'm a very happy fates user but I was looking at this and I like some of the upgrades and  the compatibility with the original hardware.

I've got a WIP design that has a dc input and power switch and I was wondering if this board will be open-sourced at the hardware level.

carlosedp, 2024-02-16:
Any expected date to release the board files as the kits are sold-out on the web store?
I'd love to build one.

cdd3, 2024-06-15:
The read-me says that the design files are "coming soon."  I'd also very much like to see them.

Pastitas, 2025-01-07:
I'd hope they're in the works, otherwise I'm not sure the licensing of the norns shield project is being complied with.

thrivewebdesign, 2025-01-09:
I asked about this a few months ago and he was just organising the kicad files so hopefully soon.

jhbruhn, 2025-03-04:
Seems to be done now.

Pastitas, 2025-03-04:
Amazing, thanks! @okyeron

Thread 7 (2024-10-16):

jack fail error?

fabiendostie, 2024-10-16:
brand new install on RPI4B+
Using the Pi4 220306 file [norns220306-shield-pi4](https://github.com/monome/norns-image/releases/download/220306/norns220306-shield-pi4-cs4270.tgz)
I get: **jack fail.** on the shieldXL screen....

fabiendostie, 2025-04-14:
---
# Still geting the Jack Fail error 🚫
## Even after the repairs that you've done on the shieldXL 🚧
* Brand new install on RPI4B+ 4 gb
* Using 5v/ 3amp power
* Good 32 gb [sandisk extreme micro sd card A1 HC1 v30](https://www.amazon.ca/SanDisk-Extreme-Mobile-Gaming-microSD/dp/B089M5KV4Y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)
* I start the installation using pi imager use the Pi4 220306 file
* Expand the filesystem

## I get the Jack Fail. error

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
---
when I try updating through the commandline via ssh using these commands (one by one):
```
cd update
wget https://github.com/monome/norns/releases/download/v2.8.1/norns231114.tgz
tar xzvf norns231114.tgz
cd 231114
./update.sh
sudo reboot now
```
* I do not get any errors on the update script.
## still get the jack fail error after reboot though
I would really like if someone could help me figure out what is the issue with this, what does it even mean?

Closed 2025-08-12.

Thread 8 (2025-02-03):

Advice: Display Never Turns On

jtschoonhoven, 2025-02-03:
I've followed the assembly videos, flashed the image, plugged it in and... nothing happens on the display. The red and green LEDs light up on the pi 3B+ itself (red is steady on, the green flashing intermittently), but the screen shows no signs of life at all.

Probably I did something wrong during the assembly, but I'd appreciate some guidance in the debugging. Currently I don't even know how to tell if it's a hardware or software issue, or if the device is working fine except for the screen.

Thanks for any help.

alex-obscure, 2025-02-03:
You can check [hardware help](https://monome.org/docs/norns/help/hardware/#boot-shield) section of Norns docs. The first thing is to check "sine-like tone which indicates the norns OS has been successfully loaded".

jtschoonhoven, 2025-02-03:
Update: after wiggling things around a bit it now looks like this:

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

Looks like it's _almost_ working. What might cause it to look corrupted in this way? I'm on a reliable power supply...

jtschoonhoven, 2025-02-06:
Closing this since it's more appropriate for the Discord

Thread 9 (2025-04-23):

Place Ferrite L3 or not?

6040, 2025-04-23:
The schematic has it placed but on the pcb it says DNP.
Should this guy be included or not?
L3,L0805,1,BLM21PG331SN1D,C74764

okyeron, 2025-04-29:
Yeah L3 should be placed.

The DNP on the pcb is for R21.

Closed 2025-04-29.

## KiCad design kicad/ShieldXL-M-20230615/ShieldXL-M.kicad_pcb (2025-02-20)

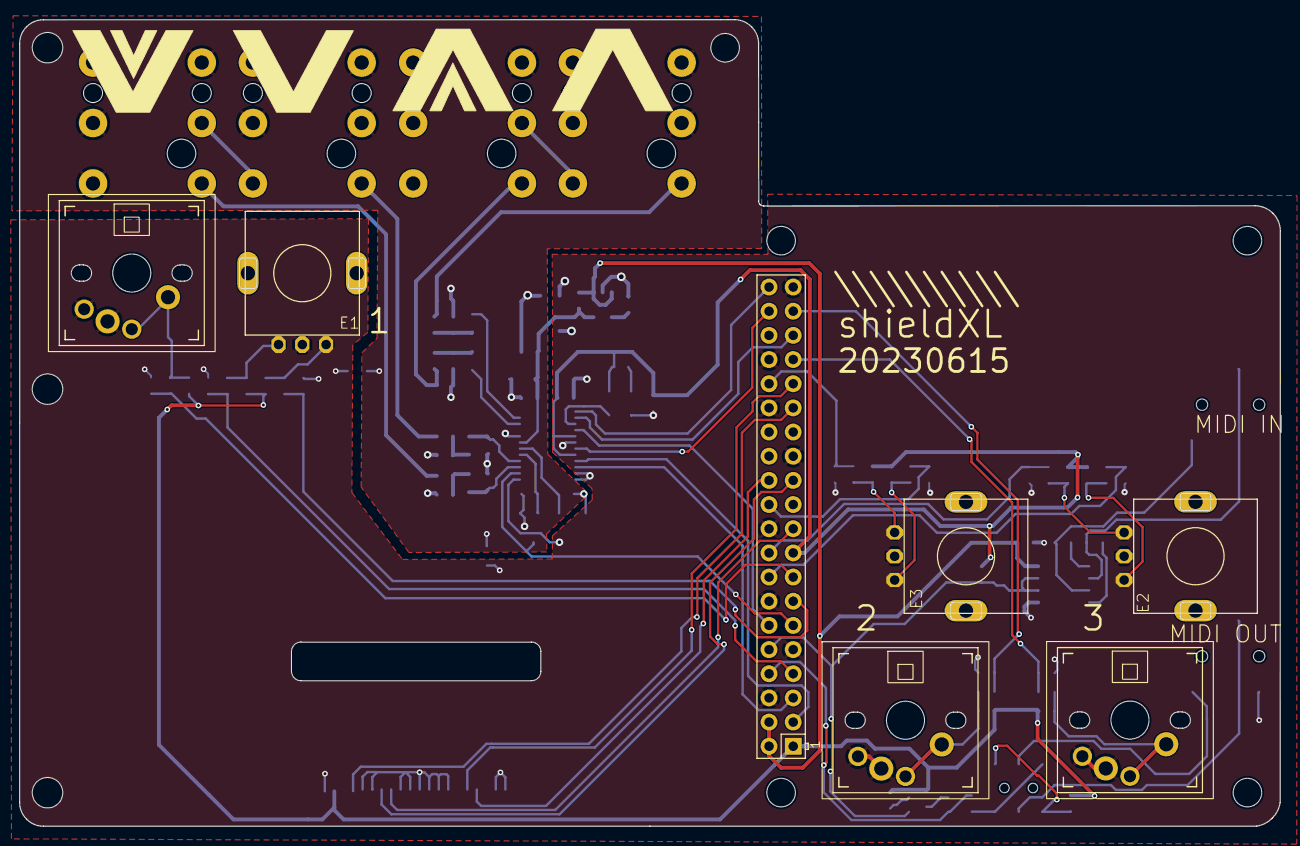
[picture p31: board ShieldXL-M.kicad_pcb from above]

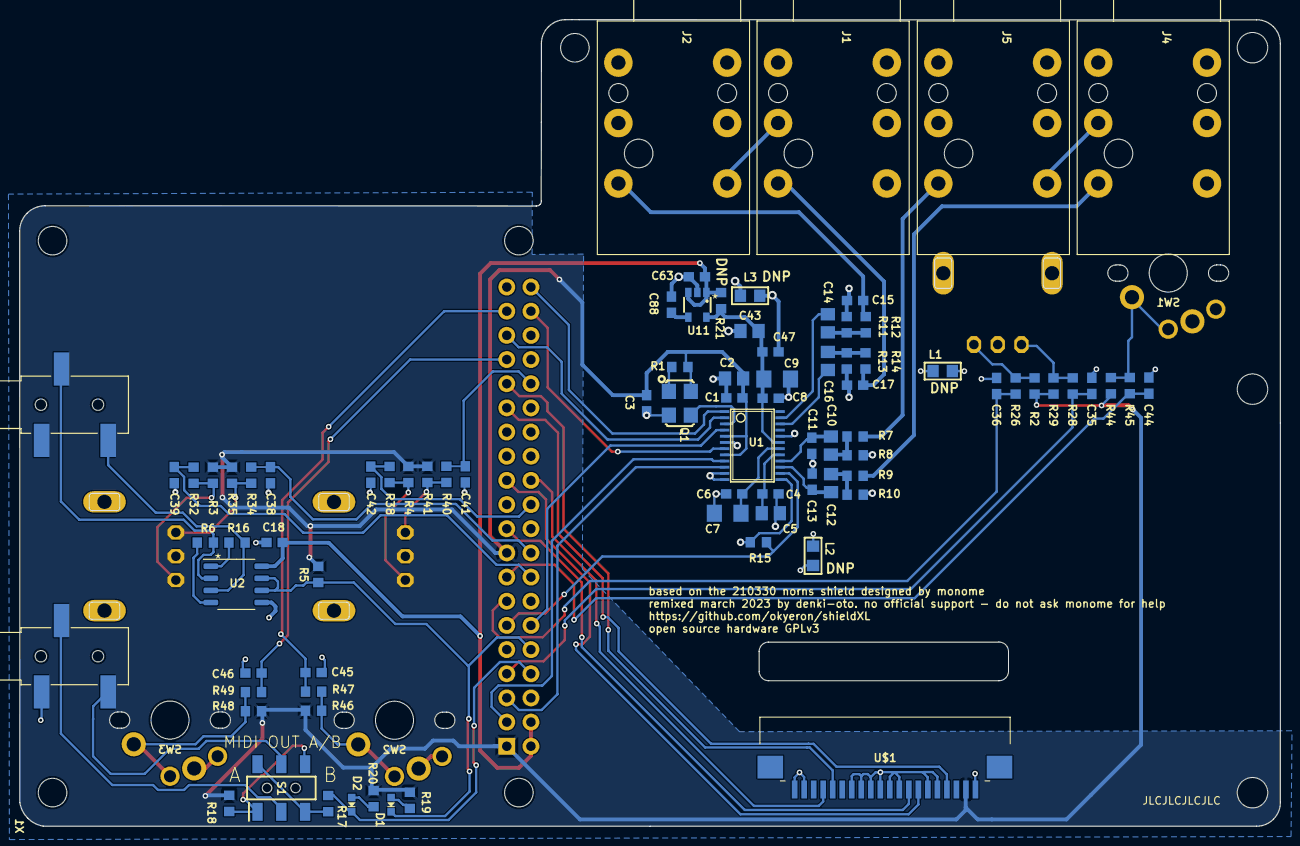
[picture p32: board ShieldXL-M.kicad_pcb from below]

Board: 2 copper layers, 132.5 x 84.8 mm, 91 parts (84 on the bottom side), 66 nets.

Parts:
C1, C4, C6, C8, C18, C47, C63: 100n; C0603
C2, C5, C10, C12, C43: 10u; C0805
C3, C35, C36, C38, C39, C41, C42, C44, C45, C46, C88: 10n; C0603
C7, C9: 47u; C1206
C11, C13: 220p COG; C0603
C14, C16: 3.3u; C0805
C15, C17: 2700p COG; C0603
D1: RED; CHIPLED_0603_NOOUTLINE
D2: BLUE; CHIPLED_0603_NOOUTLINE
E1, E2, E3: ENC; PEC11RN
J1, J2, J4, J5: NRJ6HF; Jack_6.35mm_Neutrik_NRJ6HF_Horizontal
J3, J6: PJ-320B; LUOYANG-DISHANG_PJ-320B
L1, L2: DNP; L0805
L3: FERRITE; L0805
Q1: ASFL1-12.288MHZ-LCS-T; ASF
R1, R2, R3, R4, R8, R10, R11, R13, R15, R26, R28, R29, R32, R34, R35, R38, R40, R41, R44, R45, R46, R47, R48, R49: 10k; R0603
R5: 470Ω; R0603
R6, R16: 220Ω; R0603
R7, R9: 4.99k; R0603
R12, R14: 590; R0603
R17, R18, R19: 47Ω; R0603
R20: 15Ω; R0603
R21: DNP; R0603
S1: EG1390B; SOP250P600X400-6N
SW1, SW2, SW3: PVA1; Choc_MX_combo
U1: CS4270; TSSOP24
U2: HCPL-0631-500E; SSOP-8_3.9x5.05mm_P1.27mm
U11: TPS793475DBVR; SSOP5
U$1: OLED128X64; F-FPC1M20P-B310
X1: RASPI_BOARD_B+#_E3; RASPI_BOARD_B+_EDGES_3DRILL

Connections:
+3V3: C1.1, C2.1, C3.1, Q1.4 (VCC), R1.1, R2.2, R3.2, R4.2, R5.2, R18.2, R19.2, R20.2, R29.2, R35.2, R41.2, R44.1, R46.1, R48.1, U1.5 (VD), U1.8 (VLC), U$1.2 (VDD), X1.1 (3V3A), X1.17 (3V3B)
+5V: C18.2, C63.1, R21.1, U2.8 (VCC), U11.1 (IN), U11.3 (EN), X1.2 (5V0A), X1.4 (5V0B)
/norns-shield-210330_1/A5V: C8.1, C9.1, C43.1, C47.1, R21.2, U1.19 (VA), U11.6 (OUT)
/norns-shield-210330_1/INA: C10.1, C11.1, U1.16 (AINB)
/norns-shield-210330_1/INB: C12.1, C13.1, U1.15 (AINA)
/norns-shield-210330_1/LRCK: U1.2 (LRCK), X1.35 (GPIO19)
/norns-shield-210330_1/MCLK: Q1.3 (FO), U1.3 (MCLK)
/norns-shield-210330_1/OUTA: C14.1, U1.23 (AOUTB)
/norns-shield-210330_1/OUTB: C16.1, U1.22 (AOUTA)
/norns-shield-210330_1/R-CODEC: R15.1, U1.14 (_RST), X1.11 (GPIO17)
/norns-shield-210330_1/SCL: U1.10 (CCLK), X1.5 (SCL)
/norns-shield-210330_1/SCLK: U1.4 (SCLK), X1.12 (GPIO18)
/norns-shield-210330_1/SDA: U1.9 (CDOUT), X1.3 (SDA)
/norns-shield-210330_1/SDIN: U1.1 (SDIN), X1.40 (GPIO21)
/norns-shield-210330_1/SDOUT: U1.7 (SDOUT), X1.38 (GPIO20)
/norns-shield-210330_2/RING1_4: R18.1, S1.1, S1.4
/norns-shield-210330_2/TIP1_5: R17.1, S1.3, S1.6
A1: C35.1, R28.2, X1.7 (GPIO04)
A2: C38.1, R34.2, X1.18 (GPIO24)
A3: C41.1, R40.2, X1.32 (GPIO12)
AGND: C4.2, C5.2, C6.2, C7.2, C8.2, C9.2, C11.2, C13.2, C15.2, C17.2, C47.2, J1.S, J2.R, J2.S, J4.RN, J4.S, J4.TN, J5.R, J5.RN, J5.S, L1.1, L2.1, L3.1, R8.2, R10.2, R11.2, R13.2, U1.20 (AGND)
B1: C36.1, R26.2, X1.13 (GPIO27)
B2: C39.1, R32.2, X1.16 (GPIO23)
B3: C42.1, R38.2, X1.22 (GPIO25)
CE0: U$1.17 (/CS), X1.24 (SPI_CE0)
GND: C1.2, C2.2, C3.2, C18.1, C35.2, C36.2, C38.2, C39.2, C41.2, C42.2, C43.2, C44.2, C45.2, C46.2, C63.2, C88.2, E1.GND, E2.GND, E3.GND, J3.4 (SLEEVE), L1.2, L2.2, L3.2, Q1.2 (GND), R15.2, SW1.SW2 (PIN-2), SW2.SW2 (PIN-2), SW3.SW2 (PIN-2), U1.6 (DGND), U1.11 (CS), U1.12 (CDIN), U1.13 (AD2), U2.5 (GND), U11.2 (GND), U$1.1 (VSS), U$1.5 (R/W), U$1.6 (E), U$1.9 (DB2), U$1.10 (DB3), U$1.11 (DB4), U$1.12 (DB5), U$1.13 (DB6), U$1.14 (DB7), U$1.19 (BS1), U$1.20 (BS0), X1.6 (GND_A), X1.9 (GND_B), X1.14 (GND_C), X1.20 (GND_D), X1.25 (GND_E), X1.30 (GND_F), X1.34 (GND_G), X1.39 (GND_H)
K1: C44.1, R45.2, X1.15 (GPIO22)
K2: C45.1, R47.2, X1.37 (GPIO26)
K3: C46.1, R49.2, X1.33 (GPIO13)
MIDI_RX: D1.C, R5.1, U2.6 (VO2), U2.7 (VO1), X1.10 (RXD)
MIDI_TX: D2.C, R17.2, X1.8 (TXD)
MOSI: U$1.8 (SDIN), X1.19 (SPI_MOSI)
unnamed: C10.2, R7.1, R8.1
unnamed: C12.2, R9.1, R10.1
unnamed: C14.2, R11.1, R12.1
unnamed: C15.1, J2.T, R12.2
unnamed: C16.2, R13.1, R14.1
unnamed: C17.1, J1.T, R14.2
unnamed: D1.A, R19.1
unnamed: D2.A, R20.1
unnamed: E1.A, R28.1, R29.1
unnamed: E1.B, R2.1, R26.1
unnamed: E2.A, R34.1, R35.1
unnamed: E2.B, R3.1, R32.1
unnamed: E3.A, R40.1, R41.1
unnamed: E3.B, R4.1, R38.1
unnamed: J1.R, J2.TN
unnamed: J3.3 (RING), S1.2 (2_COM)
unnamed: J3.2 (TIP), S1.5 (5_COM)
unnamed: J4.R, J5.TN
unnamed: J4.T, R9.2
unnamed: J5.T, R7.2
unnamed: J6.3 (RING), R6.1, U2.2 (CATHODE_1)
unnamed: J6.2 (TIP), R16.1, U2.3 (CATHODE_2)
unnamed: Q1.1 (OE), R1.2
unnamed: R44.2, R45.1, SW1.SW1 (PIN-1)
unnamed: R46.2, R47.1, SW2.SW1 (PIN-1)
unnamed: R48.2, R49.1, SW3.SW1 (PIN-1)
unnamed: C6.1, C7.1, U1.18 (FILT+)
unnamed: C4.1, C5.1, U1.17 (VQ)
unnamed: R16.2, U2.1 (ANODE_1)
unnamed: R6.2, U2.4 (ANODE_2)
unnamed: C88.1, U11.4 (NR)
O_DC: U$1.4 (D/C), X1.29 (GPIO05)
O_RESET: U$1.16 (/RES), X1.31 (GPIO06)
SCK: U$1.7 (SCLK), X1.23 (SPI_SCLK)

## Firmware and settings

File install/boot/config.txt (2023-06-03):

# How much memory in MB to assign to the GPU on Pi models having
# 256, 512 or 1024 MB total memory
gpu_mem_256=100
gpu_mem_512=100
gpu_mem_1024=100

# Display
# Connected using SPI
dtparam=spi=on
dtoverlay=ssd1322-spi
dtparam=rotate=180

# Soundcard
# Connected using I2S
# CS4270 codec used by soundcard connected using I2C
dtparam=i2s=on
dtparam=i2c=on
dtoverlay=monome-snd-4270

# Buttons and encoders
dtoverlay=norns-buttons-encoders
dtparam=e1_pin_a=4
dtparam=e1_pin_b=27
dtparam=e2_pin_a=12
dtparam=e2_pin_b=25
dtparam=e3_pin_a=24
dtparam=e3_pin_b=23
dtparam=b1_pin=22
dtparam=b2_pin=26
dtparam=b3_pin=13

#[rpi4]
#enable_uart=1
#uart_2ndstage=1
#arm_boost=1
enable_uart=1
dtoverlay=miniuart-bt
dtoverlay=uart0
dtoverlay=midi-uart0

kernel=kernel-5.10.92-18-v7l-g458e2253667a.img

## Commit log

2023-06-06 bom update
2023-06-08 Explain alternative display cable in BOM.
2023-06-11 change case to enclosure
2023-06-15 FPC cable info
2023-06-15 Update BOM.md
    typo
2023-06-15 Update BOM.md
    formatting
2023-06-16 add 3d case models
    [shieldXL_case_v1.1.step, shieldXL_case_v1.1_noInserts.step]
2023-06-18 update case to v1.2
    [shieldXL_case_v1.1.step, shieldXL_case_v1.1_noInserts.step, shieldXL_case_v1.2.step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]
2023-06-28 add 1.4.3 case files
    [shieldXL_case_v1.4.3_threaded.step]
2023-07-11 bom/doc updates
2023-07-12 update case files to 1.4.4
    [shieldXL_case_jp_v1.4.4_threaded.step, shieldXL_case_v1.4.3_threaded.step]
2023-07-13 remove 1.2 update readme
    [shieldXL_case_v1.2.step, shieldXL_case_v1.2_noInserts.step]
2023-07-17 Fix SVG and add DXF
    [ShieldXL-M-top-panel-19mm.dxf]
2023-07-25 Update BOM.md
    add part number for plastic jack nuts
2023-08-03 Add images to build guide, add build guide and bill of materials links to README.md
2023-08-05 Update BOM.md
    add detail for thread size
2023-08-19 add battery mod link
2023-09-03 add new case STL
    [shieldXLplate-v2.stl]
2023-10-02 update case files, readme
    [shieldXL_case_jp_v1.4.4_threaded.step, shieldXL_case_jp_v1.5.1.step]
2023-12-19 add case v1.6.1
    [shieldXL_case_jp_v1.6.1.step]
2024-01-12 reorganize top panels
    [ShieldXL-M-top-panel-19mm.dxf, ShieldXL-M-top-panel-no-window.dxf, shieldXLplate-v2.stl]
2024-03-27 Update BOM.md
    add yellow display part number
2024-03-27 Update BOM.md
    fix display link
2024-04-27 add new case files
    [shieldXL_case_jp_v1.6.4.step]
2025-01-30 update build and add shieldsaver stls
    [shieldsaver_slim.stl, shieldsaver_slim_v2.stl]
2025-01-30 add SLS STL picture
2025-01-30 fix stls
    [shieldsaver_slim.stl, shieldsaver_tall_v2.stl]
2025-02-27 update bom spreadsheets
    [shieldXL-M-20230423-TH.xlsx]
